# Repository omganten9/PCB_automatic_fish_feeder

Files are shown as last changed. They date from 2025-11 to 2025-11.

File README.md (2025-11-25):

# IoT-Based Automatic Fish Feeder System 🐟

An **IoT-integrated automatic fish feeder** designed using **ESP32** and **KiCad PCB design** to optimize aquarium maintenance.  
This project was developed as part of the *Final Project RE 2* course at Universitas Indonesia (2023).

---

## 🧠 Overview
This system enables automated and remote control of fish feeding using IoT technology.  
With motion and turbidity sensors, the feeder intelligently manages feeding schedules, monitors water conditions, and communicates through a **web server** via **Wi-Fi**.

**Key features:**
- Remote feeding schedule control via web interface  
- Real-time water turbidity monitoring  
- OLED/LCD display showing feeding status and last feeding time  
- Owner confirmation before auto-feeding for security  
- Deep sleep mode for efficient power usage  

---

## ⚙️ Hardware Summary
- **Microcontroller:** ESP32  
- **Sensors:** PIR (motion) sensor, turbidity sensor  
- **Actuators:** Servo motor (feeding mechanism), buzzer  
- **Display:** OLED / LCD  
- **Power System:** TP4056 Li-Ion charger module, 3.7V Li-ion battery  
- **Interfaces:** UART, USB Type-C (CP2104), Wi-Fi (Web Server)  

---

## 🧩 PCB Design
The PCB was designed using **KiCad** with:
- Dual-layer copper traces (signal + ground)  
- Ground filling for noise reduction and EMI suppression  
- Proper antenna clearance for ESP32 Wi-Fi module  
- Mounting holes for mechanical stability  
- Compact design for integration inside an aquarium enclosure  

---

## 🧰 Components Used
| Category | Components |
|---|---|
| Microcontroller | ESP32 |
| Sensors | PIR, Turbidity Sensor |
| Display | OLED/LCD |
| Actuators | Servo Motor, Buzzer |
| Power | TP4056, Li-ion Battery |
| Communication | CP2104 USB to UART, Wi-Fi |

---

## 📐 PCB Layout (Example)  
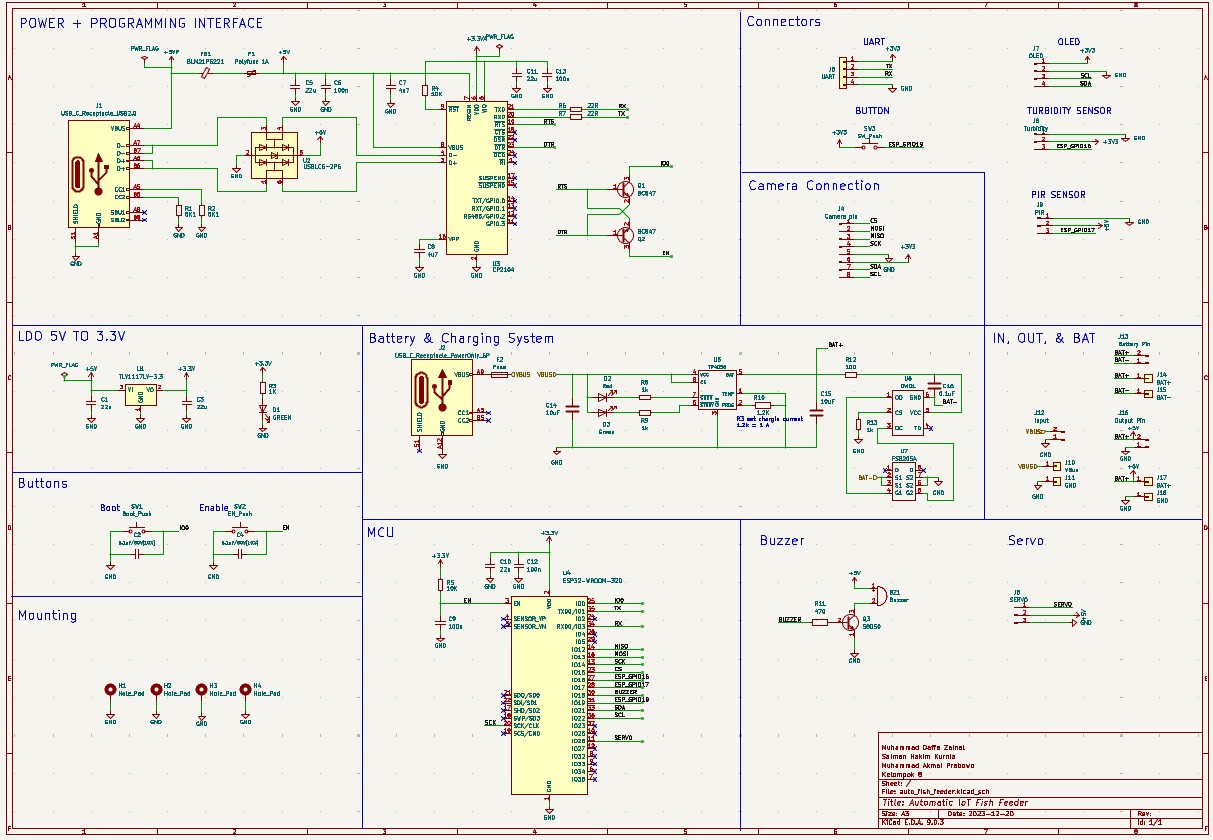
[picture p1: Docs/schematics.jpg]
PCB Schematics


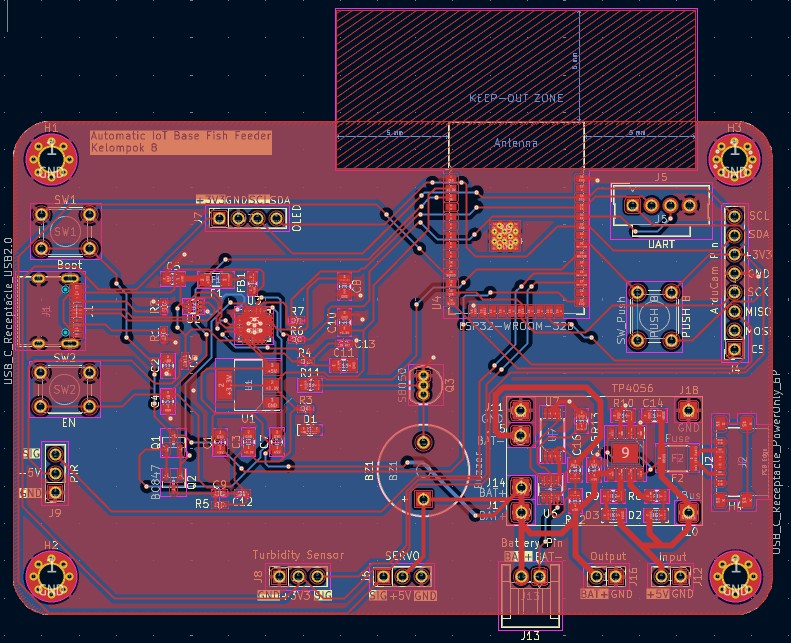
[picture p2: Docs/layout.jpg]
PCB Layout


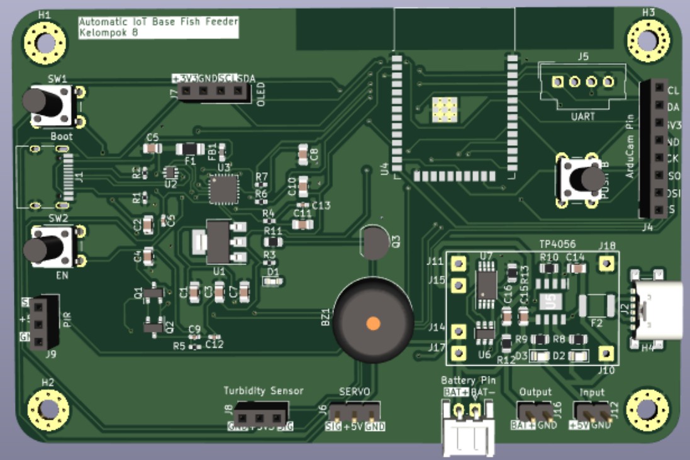
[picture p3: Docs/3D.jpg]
PCB 3D


---

## 🧾 Author & Contribution
**Team 8 – Final Project RE 2 (Universitas Indonesia, 2023)**  
- **M. Akmal Prabowo** – Schematic & PCB Design, Report (Results & Discussion)  
- **M. Daffa Zainal** – Schematic Documentation  
- **Salman Hakim Kurnia** – Feature & Component Design, Ideation, Video Editing  

---

## 📚 Reference
Full report: *Final Project RE 2 – IoT-Based Automatic Fish Feeder System (Universitas Indonesia, 2023)*  
YouTube Demo: [https://www.youtube.com/watch?v=FHcyZINsoDI](https://www.youtube.com/watch?v=FHcyZINsoDI)

---

## 📜 License
This project is for **educational and personal portfolio use only**.  
Commercial reproduction or redistribution is not permitted.

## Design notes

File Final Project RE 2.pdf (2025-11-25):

# IoT-based Automatic Fish Feeder System

Muhammad Akmal Prabowo, Muhammad Daffa Zainal, Salman Hakim Kurnia Teknik Elektro, Universitas Indonesia Jl. Lingkar, Pondok Cina, Kecamatan Beji, Kota Depok, Jawa Barat 16424 salman.hakim@ui.ac.id
muhammad.akmal12@ui.ac.id
muhammad.daffa17@ui.ac.id
Link Youtube: https://www.youtube.com/watch?v=FHcyZINsoDI

Abstrak

Sistem pemberi makan ikan otomatis berbasis IoT ini dirancang untuk memberikan pengalaman merawat ikan yang lebih efisien dan terhubung. Dengan sensor gerak, kekeruhan air, dan pemberi makan yang terkoneksi melalui modul ESP32, sistem memberikan informasi pada layar OLED/LCD tentang waktu pemberian makan terakhir, waktu berikutnya, dan kondisi air. Fitur deep sleep memungkinkan hemat daya dengan pengaturan waktu yang dapat diatur melalui menu LCD. Melalui koneksi WiFi, sistem terhubung ke web server, memberikan akses pemilik ikan untuk mengatur jadwal pemberian makan, memonitor kondisi air, dan menerima notifikasi jika kekeruhan air mencapai tingkat yang mengkhawatirkan. Keamanan ditingkatkan dengan persetujuan pemilik untuk pemberian makan otomatis. Produk ini menggabungkan kecanggihan teknologi IoT dengan kemudahan penggunaan, menciptakan solusi modern untuk perawatan ikan peliharaan dalam akuarium.

Kata kunci: Pemberi Makan Ikan Otomatis, Sistem Akuarium Berbasis IoT, Server Web ESP32

Abstract

This IoT-based automatic fish feeder system is designed to provide a more ef icient and connected experience in caring for fish. With motion sensors, water turbidity monitoring, and a feeder connected through the ESP32 module, the system displays information on an OLED/LCD screen regarding the last feeding time, the next scheduled feeding, and the water conditions. The deep sleep feature enables power savings with customizable timing settings via the LCD menu. Through WiFi connectivity, the system links to a web server, granting fish owners access to schedule feedings, monitor water conditions, and receive notifications if water turbidity reaches concerning levels. Security is enhanced with owner approval for automatic feeding. This product combines the sophistication of IoT technology with user-friendly features, creating a modern solution for the care of pet fish in aquariums.

Keywords: Automatic Fish Feeder, IoT-based Aquarium System, ESP32 Web Server

I. PENDAHULUAN

Pada era teknologi yang terus berkembang, perawatan hewan peliharaan semakin menjadi fokus inovasi. Salah satu solusi yang muncul adalah Sistem Pemberi Makan Ikan Otomatis berbasis Internet of Things (IoT). Sistem ini tidak hanya memberikan efisiensi dalam memberi makan ikan, tetapi juga menghadirkan pengalaman merawat ikan yang lebih terkoneksi.

Dengan memanfaatkan sensor gerak, sensor kekeruhan air, dan pemberi makan yang terkoneksi melalui modul ESP32, sistem ini memberikan informasi yang sangat berguna. Layar OLED/LCD menyajikan data tentang waktu pemberian makan terakhir, jadwal berikutnya, dan kondisi air, memberikan pemilik ikan pemahaman yang lebih mendalam tentang kebutuhan ikan mereka.

Fitur unggulan lainnya adalah kemampuan sistem untuk memasuki mode deep sleep, yang tidak hanya mengoptimalkan penggunaan daya, tetapi juga dapat dikonfigurasi melalui menu LCD. Koneksi WiFi memungkinkan integrasi dengan web server, memberikan pemilik akses untuk mengatur jadwal pemberian makan dan memantau kondisi air secara real-time. Keamanan ditingkatkan dengan adanya persetujuan pemilik, menegaskan kontrol atas pemberian makan otomatis.

Dengan | menggabungkan | kecanggihan
teknologi IoT dan kemudahan penggunaan, produk ini menjadi solusi modern yang menyempurnakan pengalaman merawat ikan peliharaan dalam akuarium, membawa perawatan hewan peliharaan ke tingkat baru yang lebih terhubung dan efisien.

Permasalahan:

- Tantangan pemantauan konstan dalam perawatan ikan di akuarium.
- Konsistensi dalam pemberian makan ikan menjadi kendala utama.
- Pemilik ikan membutuhkan solusi yang memudahkan mereka melakukan kontrol optimal pada ikan peliharaan mereka.

Tujuan:

- Pengembangan sistem pemberi makan ikan otomatis berbasis IoT.
- Peningkatan efisiensi pemberian makan dan konektivitas dengan pemilik ikan.
- Memberikan pengalaman merawat ikan yang lebih terkoneksi dan efisien.

### II. METODE

Proyek akhir kelompok kami melibatkan tiga tahapan/metode dalam proses perancangannya.

### 1. Rumusan Ide

Metode pengembangan proyek dimulai dengan sesi brainstorming untuk merinci cara kerja dan fitur-fitur yang akan diimplementasikan dalam rangkaian fish feeder. Ini melibatkan identifikasi sensor-sensor yang akan digunakan, serta fungsi masing-masing sensor. Proses ini didukung oleh riset untuk memastikan pemilihan komponen yang optimal. Setelahnya, komponen utama ditentukan, membentuk alur kerja sistem pemberi makan ikan otomatis berbasis IoT.

Hasil:

Proyek akan didesain untuk meningkatkan efisiensi dalam merawat ikan yang optimal dan terotomatisasi. Dengan menggunakan sensor gerak, sensor kekeruhan air, dan pemberi makan yang terhubung melalui CPU ESP32, sistem mampu menyajikan informasi pada layar OLED/LCD. Tampilan ini mencakup informasi mengenai waktu pemberian makan terakhir, jadwal pemberian makan berikutnya, dan kondisi air di dalam akuarium. Untuk efisiensi daya, sistem dilengkapi fitur deep sleep yang dapat diatur melalui menu LCD. Melalui koneksi WiFi, sistem terhubung ke web server, memungkinkan pemilik ikan mengelola jadwal pemberian makan, memantau kondisi air, dan menerima notifikasi jika kekeruhan air mencapai
tingkat | yang | mengkhawatirkan. | Keamanan
diperkuat dengan persetujuan pemilik untuk pemberian makan otomatis. Produk ini menciptakan solusi modern untuk perawatan ikan peliharaan dengan menggabungkan kecanggihan teknologi IoT dan kemudahan penggunaan.

Komponen:

- Connectors and Drivers
UART; OLED; Push Button; Turbidity Sensor; PIR Sensor; CP2104; USB Type C
- Camera
- Battery and Charging System
- Actuators
Buzzer; Servo
- Microcontroller
Core CPU ESP 32

### 2. Skematik

Berikut adalah gambaran rangkaian proyek yang telah kita desain skematiknya.

- Connectors and Camera Connection

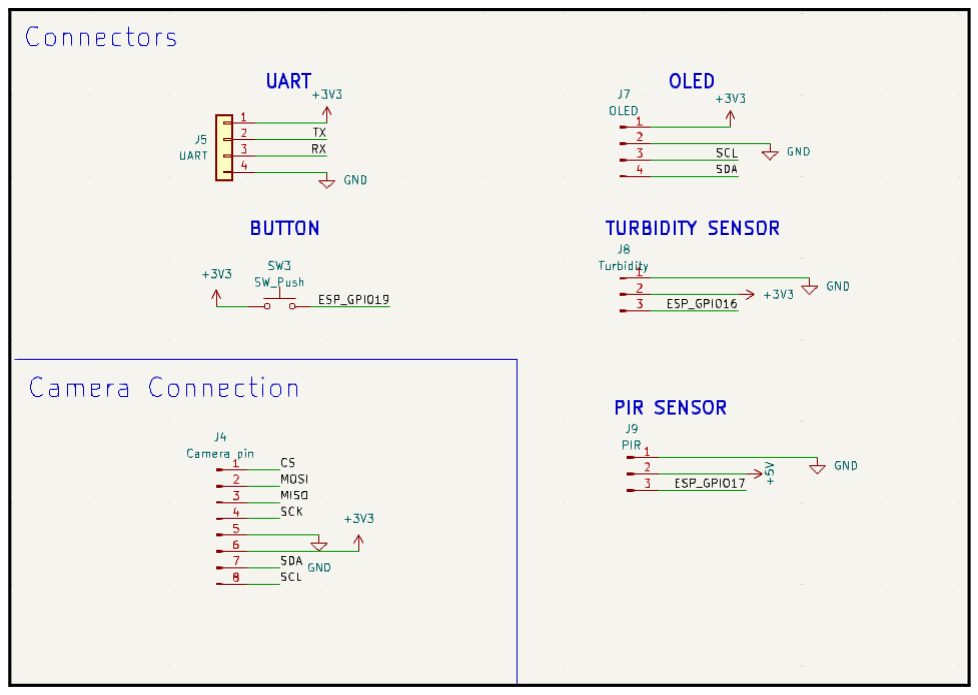
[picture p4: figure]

Pada sistem ini, digunakan UART dan connector sebagai langkah antisipatif jika jumlah pin pada PCB mencapai kapasitas maksimal, memungkinkan konektivitas dengan mikrokontroler lain untuk meningkatkan fleksibilitas. OLED display akan menampilkan informasi vital seperti waktu terakhir pemberian makan, tingkat kekeruhan air, jadwal pemberian makan selanjutnya, dan menu untuk mengatur timer. Penempatannya di atas akuarium memberikan akses mudah untuk memonitor kondisi

Turbidity sensor berfungsi mendeteksi tingkat kekeruhan air, memberikan rekomendasi pembersihan kolam, dan dapat menonaktifkan pemberian makan hingga mendapatkan konfirmasi dari pemilik melalui web server. PIR sensor mendeteksi gerakan pemilik ketika mendekati akuarium, dan informasinya diintegrasikan pada OLED untuk mengaktifkan display. Tombol manual digunakan untuk memberi makan secara langsung dan mengatur timer melalui menu.
Dengan | kombinasi | komponen | ini, | sistem
memberikan solusi yang komprehensif untuk perawatan ikan dalam akuarium.Sebagai fitur berikutnya, kamera ditambahkan untuk memberikan akses pemilik melihat kondisi kolam melalui web server, dengan kemampuan menyalakan kamera sesuai kebutuhan.
- Actuators

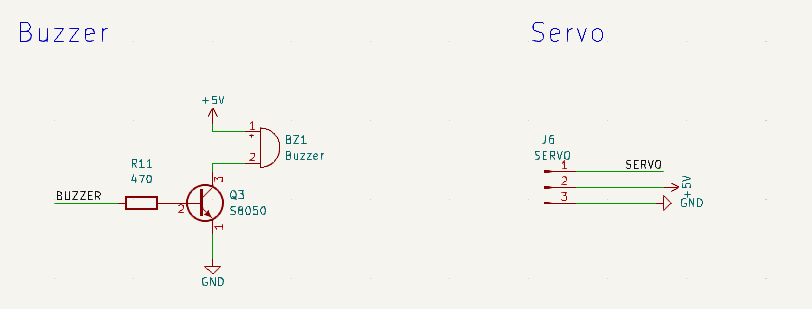
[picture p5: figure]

Buzzer pada sistem pemberi makan ikan otomatis akan aktif selama proses pemberian makan kepada ikan. Saat waktunya tiba, buzzer akan menghasilkan suara sebagai indikator bahwa proses pemberian makan sedang berlangsung. Suara ini berfungsi sebagai sinyal yang dapat diperhatikan oleh pemilik atau orang di sekitar, memberikan pemberitahuan bahwa ikan sedang menerima pakan.

Servo, di sisi lain, memiliki peran yang lebih fungsional. Servo akan bergerak untuk mengatur posisi tempat makanan yang akan diberikan kepada ikan. Ketika waktu pemberian makan tiba, servo akan menggerakkan tempat makan menuju posisi yang telah ditentukan, memungkinkan makanan ikan dilepaskan ke dalam akuarium. Dengan sinergi antara buzzer dan servo, sistem menciptakan pengalaman pemberian makan ikan otomatis yang lebih dinamis dan terkendali.

- Battery & Charging System

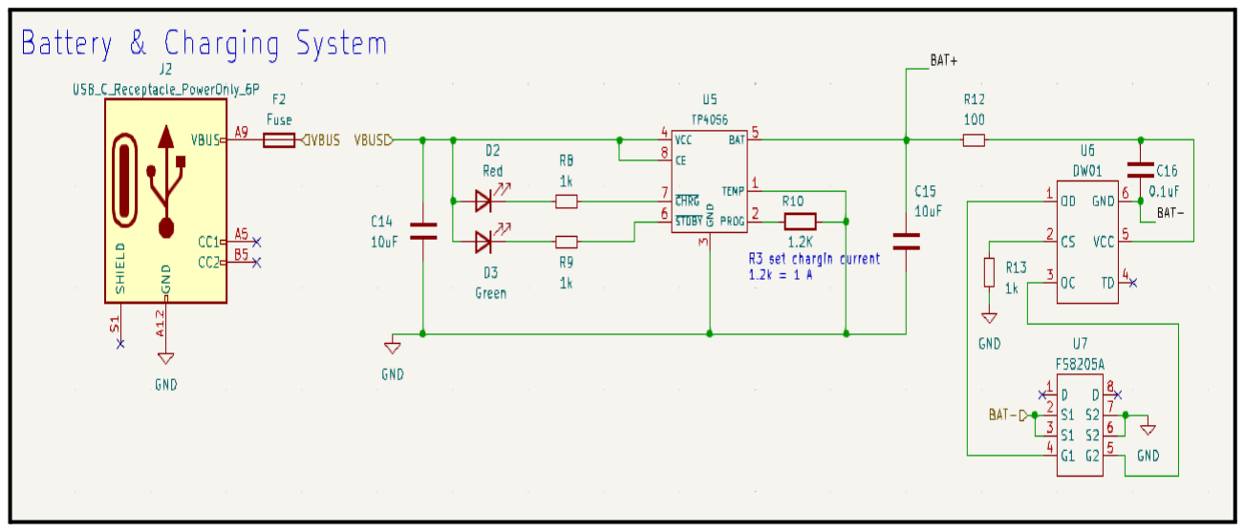
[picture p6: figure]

Pada skema battery & charging system digunakan TP4056 sebagai pengendali pengisian baterai. TP4056 adalah IC manajemen pengisian baterai yang umum digunakan dan efisien. Pada gambar kuning di sebelah kiri port USB type C yang digunakan untuk port pengisian dan koneksi ke PC atau sumber daya eksternal. CP2104 ini merupakan converter USB ke UART yang dapat

digunakan | untuk | komunikasi | dengan
mikrokontroler atau ESP32. Pada rangkaian ini terdapat indikator pengisian dengan LED indikator yang digunakan untuk menunjukan status pengisian yang mana bila LED green menyala maka baterai yang di charge sudah penuh lalu jika LED red menyala maka baterai yang di charge belum penuh. Baterai yang digunakan tidak akan rusak karena memiliki voltage regulator pada rangkaiannya yang dapat menyesuaikan voltase dari baterai ke ESP32. MCU

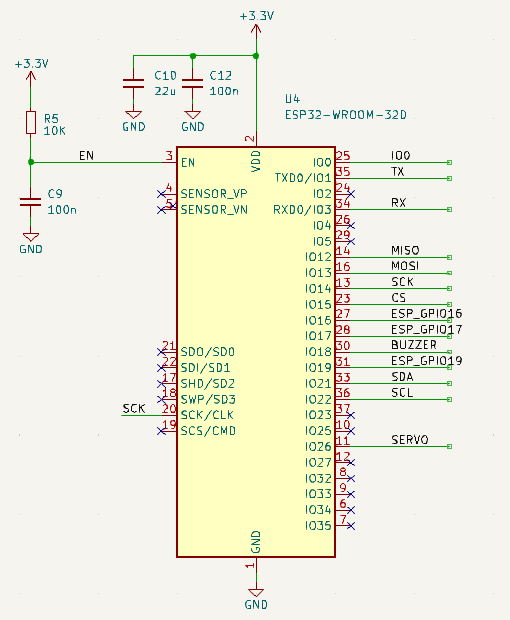
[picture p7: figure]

Dalam proyek pemberi makan ikan berbasis ESP32, penyesuaian rangkaian pin adalah proses yang penting untuk memastikan integrasi yang tepat antara perangkat keras dan mikrokontroler. ESP32 memiliki sejumlah pin dengan fungsi yang berbeda-beda, seperti GPIO (General Purpose Input/Output), ADC (Analog-to-Digital Converter), dan pin fungsi khusus seperti untuk komunikasi serial.

- LDO 5V to 3.3V

Rangkaian ini berfungsi sebagai voltage regulator yang menyesuaikan voltage input dari 5v menjadi 3.3v yang sesuai dengan ESP32.

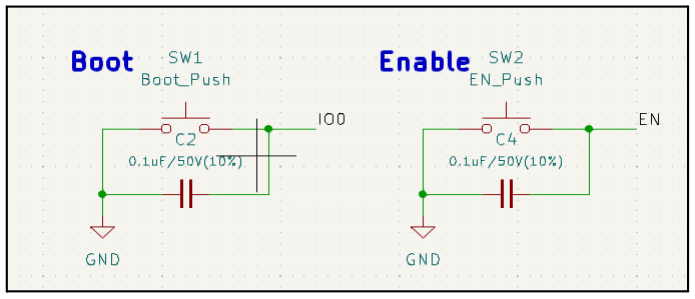
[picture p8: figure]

- Buttons
Fungsi pin boot dan enable disini ada di ESP32 dan berfungsi untuk booting dan enable untuk reset mikrokontroler.

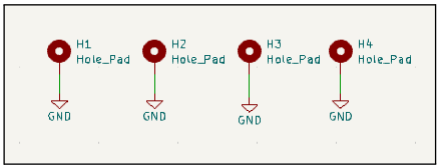
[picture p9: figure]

- Mounting
Fungsi dari proses mounting ini adalah untuk memperkuat struktur PCB dan mencegahnya agar tidak mudah goyah atau rapuh. Setiap mounting point akan saling terhubung dengan ground, memberikan stabilitas tambahan pada PCB. Hal ini bertujuan untuk menjaga kekokohan PCB agar dapat menahan tekanan atau guncangan yang mungkin terjadi selama penggunaan
- In, Out, & Bat

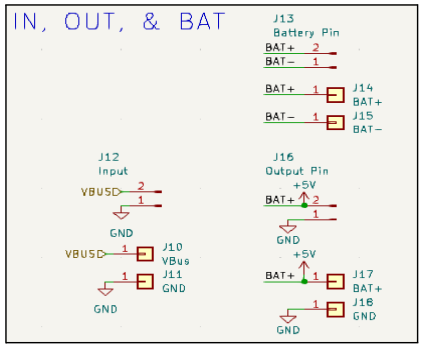
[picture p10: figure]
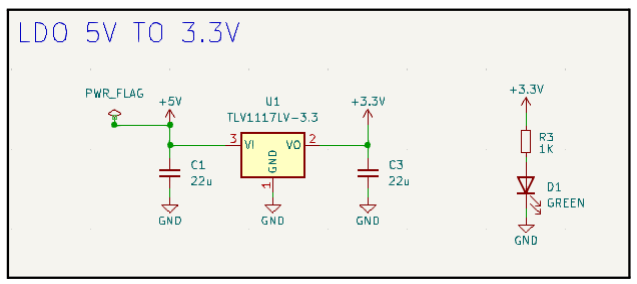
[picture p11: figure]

Pada rangkaian ini di input menunjukan input untuk charge baterainya, output pin untuk memberikan daya dari baterai ke rangkaian dan baterai pin untuk mentransfer data dari baterai ke rangkaian.

- Power and Programming Interface

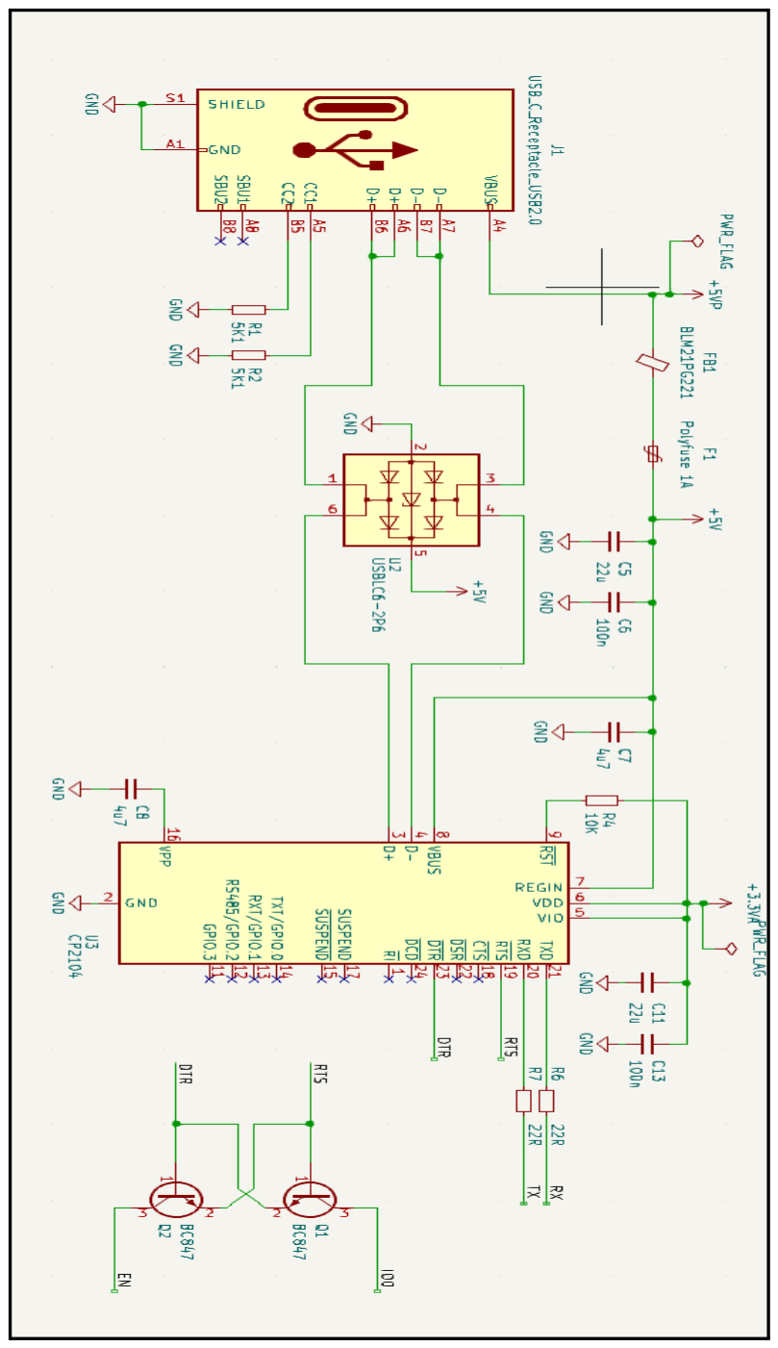
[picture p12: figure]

Pada | rangkaian | untuk | menjelaskan
programming interface dan mikrokontroler yang digunakan adalah core ESP32. Pada rangkaian terdapat CP2104 sebagai port USB-C yang berfungsi untuk mentransfer program ke ESP32. Dari data yang ada pada port CP2104 akan melewati rangkaian ESD (electrostatic discharge) yang fungsinya sebagai proteksi ketika ESP32 disentuh tidak terjadi sengatan listrik.

Pada bagian kanan terdapat rangkaian RTS dan DTR, kedua pin ini terdapat pada pin enable dan GPI0 yang fungsinya untuk memberikan sinyal switch pada ESP32 kapan data dapat ditransfer dan receive sinyal.

### III. RESULT AND DISCUSSIONS

Hasil desain skematik yang telah dirancang selanjutnya akan dibuat suatu layout Printed Circuit Board (PCB) dimana akan dibuat jalur tembaga yang akan menghubungkan tiap komponen yang digunakan dan diintegrasikan hanya dalam satu PCB. Nantinya PCB tersebut akan menjadi papan
utama | yang | terhubung | dengan
komponen-komponen lain seperti sensor, aktuator (servo), serta OLED display.
A. Layout PCB

Tampilan layout PCB diatas memiliki ukuran panjang 10,03 cm dan lebar 6,56 cm. Pada setiap sudut PCB dibuat hole pad yang akan digunakan untuk mempermudah PCB melakukan mounting pada casing yang akan digunakan nantinya. Mounting pada casing dilakukan agar PCB dapat lebih kokoh dan terlindungi selama produk digunakan.
PCB ini menggunakan dua layer atau lapisan tembaga yang pada tampilan layout

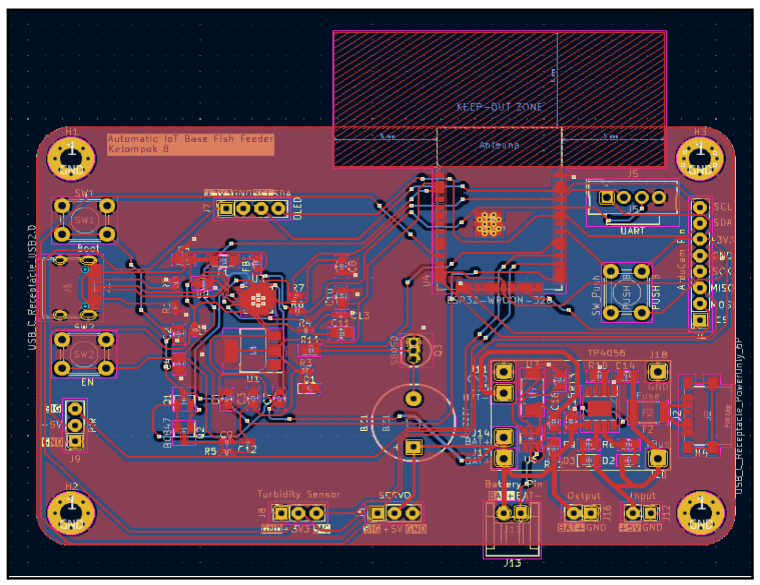
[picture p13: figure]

dibedakan berdasarkan warna merah dan biru. Jalur berwarna merah merupakan jalur tembaga pada layer pertama (diatas layer kedua) sedangkan jalur berwarna biru terletak pada layer kedua. Kedua jalur ini juga dapat saling terhubung melalui koneksi vias. Via dapat digunakan untuk
menghubungkan | koneksi | antar layer yaitu
menghubungkan antara jalur tembaga pada layer pertama (jalur merah) dan layer kedua (jalur biru).
Selain | itu, | via | juga | digunakan | untuk
menghubungkan pin ground pada komponen agar dapat terhubung pada suatu acuan ground yang sama.
Pada layout ini, dapat diamati untuk setiap pin ground pada komponen tidak saling terhubung melalui garis-garis jalur tembaga melainkan dihubungkan melalui suatu ground filling. Teknik ground filling dilakukan dengan mengisi area kosong di antara jalur-jalur konduktor dengan bidang tembaga yang berfungsi sebagai ground. Teknik ini juga dapat membantu mengurangi
impedansi | jalur, | mengurangi | interferensi
elektromagnetik, | dan | meningkatkan | kinerja
keseluruhan sirkuit.
Pada komponen chip ESP 32, terdapat kustomisasi khusus terutama pada bagian antena dimana pada area tersebut tidak terdapat jalur tembaga sama sekali. Hal ini dilakukan untuk mencegah terjadinya interferensi sinyal WiFi sehingga dapat bekerja secara maksimal. Daerah tanpa lapisan tembaga ini juga diterapkan dalam radius 5 mm dari lokasi antena.
B. Tampilan PCB secara 3D

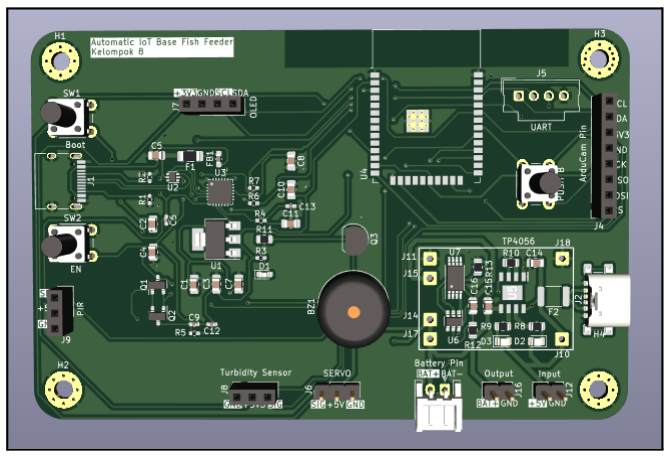
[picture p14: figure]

Tampilan 3D diatas merupakan wujud bentuk PCB yang telah dihubungkan juga dengan beberapa komponen. Peletakan pin-pin yang menjadi konektor dengan komponen eksternal seperti sensor serta aktuator juga diletakan di pinggir PCB untuk mempermudah mengoneksikan dan mencegah terjadinya pemusatan kabel yang membuat rangkaian menjadi kurang rapi. Bentuk pin atau header pada PCB juga telah disesuaikan dengan bentuk soket yang digunakan di setiap komponen sehingga mempermudah pengguna agar langsung dapat mengkoneksikan komponen dengan mudah.
Pada | lapisan | silkscreen juga telah
dimodifikasi untuk menampilkan tulisan yang digunakan sebagai petunjuk setiap pin yang
digunakan | agar | memperkecil | kemungkinan
terjadinya salah hubung yang akan merusak komponen serta rangkaian nantinya. PCB ini didesain seefisien mungkin baik dari segi perakitan, peletakan komponen hingga mempermudah dalam segi penyolderan serta dalam segi user interface yang mudah digunakan.

IV. MEMBER CONTRIBUTION

Nama | Kontribusi
M. Akmal Prabowo | 1. Membuat skematik dan layout PCB
2. Membuat makalah
| pada bagian result and discussion
M. Daffa Zainal | 1. Membuat makalah pada bagian Skematik
Salman Hakim Kurnia | 1. Membantu perancangan fitur - fitur serta komponen yang digunakan
2. Membuat laporan
| bagian ide dan penjelasan skematik
3. Edit video
| pemaparan

REFERENSI

[1] Salman Hakim K, “Final Project Kelompok 08 -IoT-based Automatic Fish Feeder System,” YouTube. Dec. 20, 2023. Accessed: Dec. 20, 2023.
[YouTube | Video]. | Available:
https://www.youtube.com/watch?v=FHcyZINsoDI
[2] "A New Method for PCB Manufacturing Process Optimization" oleh K. Kim, S. Lee, dan J. Park, diterbitkan di Advanced Packaging, Vol. 28, No. 1, 2023.
[3] Silicon Labs. (2022). CP2104 USB to UART Bridge. Rev. 1.1. Silicon Laboratories Inc. Available:

https://www.alldatasheet.com/datasheet-pdf/pdf/466034/SILABS/CP2104.html (https://www.alldatasheet.com/datasheet-pdf/pdf/466034/SILABS/CP2104.html)
[4] Tpower Technology Inc. (2022). TP4056 Li-Ion Battery Charger. Rev. 1.2. Microchip Technology
Inc. | Available:
https://www.alldatasheet.com/datasheet-pdf/pdf/1133270/TPOWER/TP4056.html (https://www.alldatasheet.com/datasheet-pdf/pdf/1133270/TPOWER/TP4056.html)
[5] Muhammad Akmal P, “Final Project Kelompok 08 -IoT-based Automatic Fish Feeder System,” GDrive. Dec. 20, 2023. Accessed: Dec. 20, 2023. https://drive.google.com/drive/folders/1-bxF5896I-lLR-JYfGeaOg9YBJ6BsslG?usp=sharing (https://drive.google.com/drive/folders/1-bxF5896I-lLR-JYfGeaOg9YBJ6BsslG?usp=sharing)

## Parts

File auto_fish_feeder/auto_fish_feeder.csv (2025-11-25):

Source: | D:\KULIAH\SMT 5\RE 2\pcb\finprojadi\finprojadi.kicad_sch
Date: | 19/12/2023 20:17:49
Tool: | Eeschema 7.0.9
Generator: | C:\Program Files\KiCad\7.0\bin\scripting\plugins/bom_csv_grouped_by_value_with_fp.py
Component Count: | 70
Ref | Qnty | Value | Cmp name | Footprint | Description | Vendor | DNP
BZ1 | 1 | Buzzer | Buzzer | Buzzer_Beeper:Buzzer_12x9.5RM7.6 | Buzzer, polarized
C1, C3, C10, C11 | 4 | 22u | C_Small | Capacitor_SMD:C_0805_2012Metric_Pad1.18x1.45mm_HandSolder | Unpolarized capacitor, small symbol
C2, C4 | 2 | 0.1uF/50V(10%) | C_Small | Capacitor_SMD:C_0805_2012Metric | Unpolarized capacitor, small symbol
C5 | 1 | 22u | C_Small | Capacitor_SMD:C_0805_2012Metric | Unpolarized capacitor, small symbol
C6, C9, C12, C13 | 4 | 100n | C_Small | Capacitor_SMD:C_0402_1005Metric_Pad0.74x0.62mm_HandSolder | Unpolarized capacitor, small symbol
C7, C8 | 2 | 4u7 | C_Small | Capacitor_SMD:C_0805_2012Metric_Pad1.18x1.45mm_HandSolder | Unpolarized capacitor, small symbol
C14, C15 | 2 | 10uF | C | Capacitor_SMD:C_0805_2012Metric | Unpolarized capacitor
C16 | 1 | 0.1uF | C | Capacitor_SMD:C_0805_2012Metric | Unpolarized capacitor
D1 | 1 | GREEN | LED | LED_SMD:LED_0603_1608Metric_Pad1.05x0.95mm_HandSolder | Light emitting diode
D2 | 1 | Red | LED | LED_SMD:LED_0805_2012Metric | Light emitting diode
D3 | 1 | Green | LED | LED_SMD:LED_0805_2012Metric | Light emitting diode
F1 | 1 | Polyfuse 1A | Polyfuse_Small | Fuse:Fuse_1206_3216Metric_Pad1.42x1.75mm_HandSolder | Resettable fuse, polymeric positive temperature coefficient, small symbol
F2 | 1 | Fuse | Fuse | Fuse:Fuse_1812_4532Metric | Fuse
FB1 | 1 | BLM21PG221 | FerriteBead_Small | Inductor_SMD:L_0603_1608Metric_Pad1.05x0.95mm_HandSolder | Ferrite bead, small symbol
H1, H2, H3, H4 | 4 | Hole_Pad | MountingHole_Pad | MountingHole:MountingHole_3.2mm_M3_Pad_Via | Mounting Hole with connection
J1 | 1 | USB_C_Receptacle_USB2.0 | USB_C_Receptacle_USB2.0 | Connector_USB:USB_C_Receptacle_HRO_TYPE-C-31-M-12 | USB 2.0-only Type-C Receptacle connector
J2 | 1 | USB_C_Receptacle_PowerOnly_6P | USB_C_Receptacle_PowerOnly_6P | Connector_USB:USB_C_Receptacle_GCT_USB4135-GF-A_6P_TopMnt_Horizontal | USB Power-Only 6P Type-C Receptacle connector
J4 | 1 | Camera pin | Conn_01x08_Pin | Connector_PinSocket_2.54mm:PinSocket_1x08_P2.54mm_Vertical | Generic connector, single row, 01x08, script generated
J5 | 1 | UART | Conn_01x04 | Connector_Molex:Molex_SL_171971-0004_1x04_P2.54mm_Vertical | Generic connector, single row, 01x04, script generated (kicad-library-utils/schlib/autogen/connector/)
J6 | 1 | SERVO | Conn_01x03_Pin | Connector_PinHeader_2.54mm:PinHeader_1x03_P2.54mm_Vertical | Generic connector, single row, 01x03, script generated
J7 | 1 | OLED | Conn_01x04_Pin | Connector_PinSocket_2.54mm:PinSocket_1x04_P2.54mm_Vertical | Generic connector, single row, 01x04, script generated
J8 | 1 | Turbidity | Conn_01x03_Pin | Connector_PinSocket_2.54mm:PinSocket_1x03_P2.54mm_Vertical | Generic connector, single row, 01x03, script generated
J9 | 1 | PIR | Conn_01x03_Pin | Connector_PinSocket_2.54mm:PinSocket_1x03_P2.54mm_Vertical | Generic connector, single row, 01x03, script generated
J10 | 1 | VBus | Conn_01x01 | Connector_Wire:SolderWire-0.5sqmm_1x01_D0.9mm_OD2.3mm | Generic connector, single row, 01x01, script generated (kicad-library-utils/schlib/autogen/connector/)
J11, J18 | 2 | GND | Conn_01x01 | Connector_Wire:SolderWire-0.5sqmm_1x01_D0.9mm_OD2.3mm | Generic connector, single row, 01x01, script generated (kicad-library-utils/schlib/autogen/connector/)
J12 | 1 | Input | Conn_01x02_Pin | Connector_PinHeader_2.54mm:PinHeader_1x02_P2.54mm_Vertical | Generic connector, single row, 01x02, script generated
J13 | 1 | Battery Pin | Conn_01x02_Pin | Connector_JST:JST_EH_S2B-EH_1x02_P2.50mm_Horizontal | Generic connector, single row, 01x02, script generated
J14, J17 | 2 | BAT+ | Conn_01x01 | Connector_Wire:SolderWire-0.5sqmm_1x01_D0.9mm_OD2.3mm | Generic connector, single row, 01x01, script generated (kicad-library-utils/schlib/autogen/connector/)
J15 | 1 | BAT- | Conn_01x01 | Connector_Wire:SolderWire-0.5sqmm_1x01_D0.9mm_OD2.3mm | Generic connector, single row, 01x01, script generated (kicad-library-utils/schlib/autogen/connector/)
J16 | 1 | Output Pin | Conn_01x02_Pin | Connector_PinHeader_2.54mm:PinHeader_1x02_P2.54mm_Vertical | Generic connector, single row, 01x02, script generated
Q1, Q2 | 2 | BC847 | BC847 | Package_TO_SOT_SMD:SOT-23 | 0.1A Ic, 45V Vce, NPN Transistor, SOT-23
Q3 | 1 | S8050 | S8050 | Package_TO_SOT_THT:TO-92_Inline | 0.7A Ic, 20V Vce, Low Voltage High Current NPN Transistor, TO-92
R1, R2 | 2 | 5K1 | R_Small | Resistor_SMD:R_0402_1005Metric_Pad0.72x0.64mm_HandSolder | Resistor, small symbol
R3 | 1 | 1K | R_Small | Resistor_SMD:R_0402_1005Metric_Pad0.72x0.64mm_HandSolder | Resistor, small symbol
R4, R5 | 2 | 10K | R_Small | Resistor_SMD:R_0402_1005Metric_Pad0.72x0.64mm_HandSolder | Resistor, small symbol
R6, R7 | 2 | 22R | R_Small | Resistor_SMD:R_0402_1005Metric_Pad0.72x0.64mm_HandSolder | Resistor, small symbol
R8, R9, R13 | 3 | 1k | R_Small | Resistor_SMD:R_0805_2012Metric | Resistor, small symbol
R10 | 1 | 1.2K | R | Resistor_SMD:R_0805_2012Metric | Resistor
R11 | 1 | 470 | R | Resistor_SMD:R_0805_2012Metric | Resistor
R12 | 1 | 100 | R_Small | Resistor_SMD:R_0805_2012Metric | Resistor, small symbol
SW1 | 1 | Boot_Push | SW_Push | Button_Switch_THT:SW_PUSH_6mm_H13mm | Push button switch, generic, two pins
SW2 | 1 | EN_Push | SW_Push | Button_Switch_THT:SW_PUSH_6mm_H13mm | Push button switch, generic, two pins
SW3 | 1 | SW_Push | SW_Push | Button_Switch_THT:SW_PUSH_6mm_H13mm | Push button switch, generic, two pins
U1 | 1 | TLV1117LV-3.3 | LM1117MP-3.3 | Package_TO_SOT_SMD:SOT-223-3_TabPin2 | 800mA Low-Dropout Linear Regulator, 3.3V fixed output, SOT-223
U2 | 1 | USBLC6-2P6 | USBLC6-2P6 | Package_TO_SOT_SMD:SOT-666 | Very low capacitance ESD protection diode, 2 data-line, SOT-666
U3 | 1 | CP2104 | CP2104 | Package_DFN_QFN:QFN-24-1EP_4x4mm_P0.5mm_EP2.6x2.6mm | Single-Chip USB-to-UART Bridge, USB 2.0 Full-Speed, 2Mbps UART, QFN-24
U4 | 1 | ESP32-WROOM-32D | ESP32-WROOM-32D | RF_Module:ESP32-WROOM-32D | RF Module, ESP32-D0WD SoC, Wi-Fi 802.11b/g/n, Bluetooth, BLE, 32-bit, 2.7-3.6V, onboard antenna, SMD
U5 | 1 | TP4056 | TP4056 | TP4056:SOIC127P600X175-9N | TP4056
U6 | 1 | DW01 | DW01 | Package_TO_SOT_SMD:SOT-23-6
U7 | 1 | FS8205A | FS8205 | Package_SO:TSSOP-8_4.4x3mm_P0.65mm

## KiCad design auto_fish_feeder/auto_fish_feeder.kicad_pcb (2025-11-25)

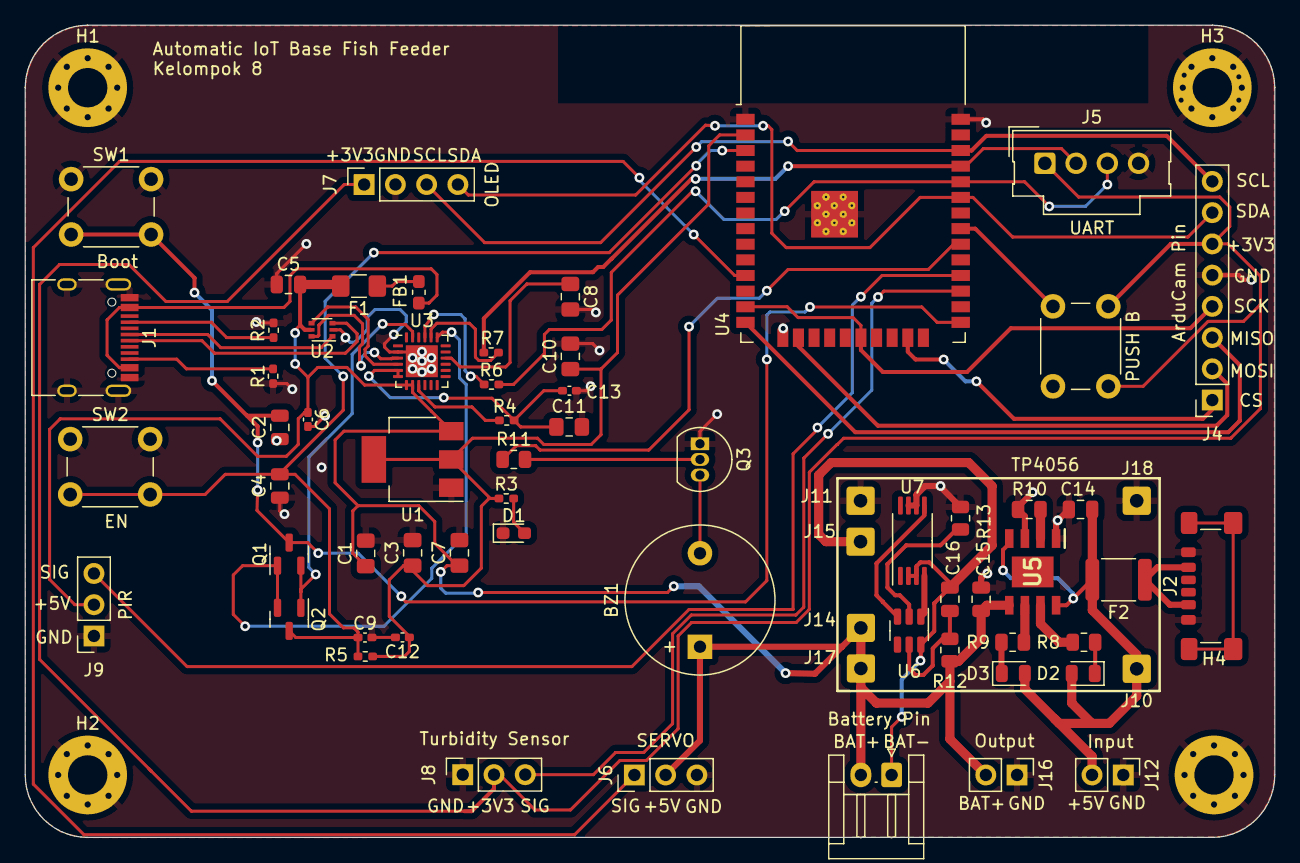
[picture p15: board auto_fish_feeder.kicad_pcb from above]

Board: 2 copper layers, 101.6 x 66.0 mm, 70 parts (0 on the bottom side), 49 nets.

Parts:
BZ1: Buzzer; Buzzer_12x9.5RM7.6
C1, C3, C10, C11: 22u; C_0805_2012Metric_Pad1.18x1.45mm_HandSolder
C2, C4: 0.1uF/50V(10%); C_0805_2012Metric
C5: 22u; C_0805_2012Metric
C6, C9, C12, C13: 100n; C_0402_1005Metric_Pad0.74x0.62mm_HandSolder
C7, C8: 4u7; C_0805_2012Metric_Pad1.18x1.45mm_HandSolder
C14, C15: 10uF; C_0805_2012Metric
C16: 0.1uF; C_0805_2012Metric
D1: GREEN; LED_0603_1608Metric_Pad1.05x0.95mm_HandSolder
D2: Red; LED_0805_2012Metric
D3: Green; LED_0805_2012Metric
F1: Polyfuse 1A; Fuse_1206_3216Metric_Pad1.42x1.75mm_HandSolder
F2: Fuse; Fuse_1812_4532Metric
FB1: BLM21PG221; L_0603_1608Metric_Pad1.05x0.95mm_HandSolder
H1, H2, H3, H4: Hole_Pad; MountingHole_3.2mm_M3_Pad_Via
J1: USB_C_Receptacle_USB2.0; USB_C_Receptacle_HRO_TYPE-C-31-M-12
J2: USB_C_Receptacle_PowerOnly_6P; USB_C_Receptacle_GCT_USB4135-GF-A_6P_TopMnt_Horizontal
J4: Camera pin; PinSocket_1x08_P2.54mm_Vertical
J5: UART; Molex_SL_171971-0004_1x04_P2.54mm_Vertical
J6: SERVO; PinHeader_1x03_P2.54mm_Vertical
J7: OLED; PinSocket_1x04_P2.54mm_Vertical
J8: Turbidity Sensor; PinSocket_1x03_P2.54mm_Vertical
J9: PIR; PinSocket_1x03_P2.54mm_Vertical
J10: VBus; SolderWire-0.5sqmm_1x01_D0.9mm_OD2.3mm
J11, J18: GND; SolderWire-0.5sqmm_1x01_D0.9mm_OD2.3mm
J12: Input; PinHeader_1x02_P2.54mm_Vertical
J13: Battery Pin; JST_EH_S2B-EH_1x02_P2.50mm_Horizontal
J14, J17: BAT+; SolderWire-0.5sqmm_1x01_D0.9mm_OD2.3mm
J15: BAT-; SolderWire-0.5sqmm_1x01_D0.9mm_OD2.3mm
J16: Output; PinHeader_1x02_P2.54mm_Vertical
PUSH B: SW_Push; SW_PUSH_6mm_H13mm
Q1, Q2: BC847; SOT-23
Q3: S8050; TO-92_Inline
R1, R2: 5K1; R_0402_1005Metric_Pad0.72x0.64mm_HandSolder
R3: 1K; R_0402_1005Metric_Pad0.72x0.64mm_HandSolder
R4, R5: 10K; R_0402_1005Metric_Pad0.72x0.64mm_HandSolder
R6, R7: 22R; R_0402_1005Metric_Pad0.72x0.64mm_HandSolder
R8, R9, R13: 1k; R_0805_2012Metric
R10: 1.2K; R_0805_2012Metric
R11: 470; R_0805_2012Metric
R12: 100; R_0805_2012Metric
SW1: Boot; SW_PUSH_6mm_H13mm
SW2: EN; SW_PUSH_6mm_H13mm
U1: TLV1117LV-3.3; SOT-223-3_TabPin2
U2: USBLC6-2P6; SOT-666
U3: CP2104; QFN-24-1EP_4x4mm_P0.5mm_EP2.6x2.6mm
U4: ESP32-WROOM-32D
U5: TP4056; SOIC127P600X175-9N
U6: DW01; SOT-23-6
U7: FS8205A; TSSOP-8_4.4x3mm_P0.65mm

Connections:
+3.3V: C3.1, C10.1, C12.1, R3.1, R5.1, U1.2 (VO), U4.2 (VDD)
+3.3VA: C11.1, C13.1, R4.1, U3.5 (VIO), U3.6 (VDD)
+3V3: J4.6, J5.1, J7.1, J8.2, PUSH B.1
+5V: BZ1.1 (-), C1.1, C5.1, C6.1, C7.1, C15.1, F1.2, J6.2, J9.2, J13.2, J14.1, J16.2, J17.1, R12.1, U1.3 (VI), U2.5 (VBUS), U3.7 (REGIN), U3.8 (VBUS), U5.5 (BAT)
+5VP: FB1.1, J1.A4 (VBUS), J1.A9 (VBUS), J1.B4 (VBUS), J1.B9 (VBUS)
/BAT-: C16.1, J13.1, J15.1, U6.6 (GND), U7.2 (S1), U7.3 (S1)
/BUZZER: R11.1, U4.30 (IO18)
/CS: J4.1, U4.23 (IO15)
/DTR: Q1.2 (E), Q2.1 (B), U3.23 (~DTR)
/EN: C4.2, C9.1, Q2.3 (C), R5.2, SW2.2, U4.3 (EN)
/ESP_GPIO16: J8.3, U4.27 (IO16)
/ESP_GPIO17: J9.3, U4.28 (IO17)
/ESP_GPIO19: PUSH B.2, U4.31 (IO19)
/IO0: C2.2, Q1.3 (C), SW1.2, U4.25 (IO0)
/MISO: J4.3, U4.14 (IO12)
/MOSI: J4.2, U4.16 (IO13)
/RTS: Q1.1 (B), Q2.2 (E), U3.19 (~RTS)
/RX: J5.3, R6.2, U4.34 (RXD0/IO3)
/SCK: J4.4, U4.13 (IO14), U4.20 (SCK/CLK)
/SCL: J4.8, J7.3, U4.36 (IO22)
/SDA: J4.7, J7.4, U4.33 (IO21)
/SERVO: J6.1, U4.11 (IO26)
/TX: J5.2, R7.2, U4.35 (TXD0/IO1)
/VBUS: C14.1, D2.2 (A), D3.2 (A), F2.2, J10.1, J12.2, U5.4 (VCC), U5.8 (CE)
GND: C1.2, C2.1, C3.2, C4.1, C5.2, C6.2, C7.2, C8.2, C9.2, C10.2, C11.2, C12.2, C13.2, C14.2, C15.2, D1.1 (K), H1.1, H2.1, H3.1, H4.1, J1.A1 (GND), J1.A12 (GND), J1.B1 (GND), J1.B12 (GND), J1.S1 (SHIELD), J2.A12 (GND), J2.B12 (GND), J4.5, J5.4, J6.3, J7.2, J8.1, J9.1, J11.1, J12.1, J16.1, J18.1, Q3.1 (E), R1.2, R2.2, R10.2, R13.2, SW1.1, SW2.1, U1.1 (GND), U2.2 (GND), U3.2 (GND), U3.25 (GND), U4.1 (GND), U4.15 (GND), U4.38 (GND), U4.39 (GND), U5.1 (TEMP), U5.3 (GND), U7.6 (S2), U7.7 (S2)
unnamed: BZ1.2 (+), Q3.3 (C)
unnamed: D1.2 (A), R3.2
unnamed: D2.1 (K), R8.1
unnamed: D3.1 (K), R9.2
unnamed: F1.1, FB1.2
unnamed: F2.1, J2.A9 (VBUS), J2.B9 (VBUS)
unnamed: J1.A5 (CC1), R2.1
unnamed: J1.B5 (CC2), R1.1
unnamed: J1.A6 (D+), J1.B6 (D+), U2.1 (I/O1)
unnamed: J1.A7 (D-), J1.B7 (D-), U2.3 (I/O2)
unnamed: Q3.2 (B), R11.2
unnamed: U2.6 (I/O1), U3.3 (D+)
unnamed: U2.4 (I/O2), U3.4 (D-)
unnamed: R7.1, U3.20 (RXD)
unnamed: R6.1, U3.21 (TXD)
unnamed: C8.1, U3.16 (VPP)
unnamed: R4.2, U3.9 (~RST)
unnamed: R10.1, U5.2 (PROG)
unnamed: R8.2, U5.7 (~CHRG)
unnamed: R9.1, U5.6 (~STDBY)
unnamed: R13.1, U6.2 (CS)
unnamed: U6.3 (OC), U7.5 (G2)
unnamed: U6.1 (OD), U7.4 (G1)
unnamed: C16.2, R12.2, U6.5 (VCC)
